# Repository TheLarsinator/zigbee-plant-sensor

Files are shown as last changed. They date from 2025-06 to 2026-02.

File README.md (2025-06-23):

# Zigbee Plant Sensor

This repository contains a project for creating a Zigbee Plant Sensor end device. The end goal is to create an energy efficient, battery powered solution for monitoring house plants. The device should be battery powered, and ideally last 2 months on a 1200 mAh battery.

When installed and powered, the device will report:

- Soil Moisture
- Illuminance
- Ambient Temperature
- Ambient Humidity
- Remaining Battery

The project is tested and developed for integrating with Zigbee2MQTT and Home Assistant.

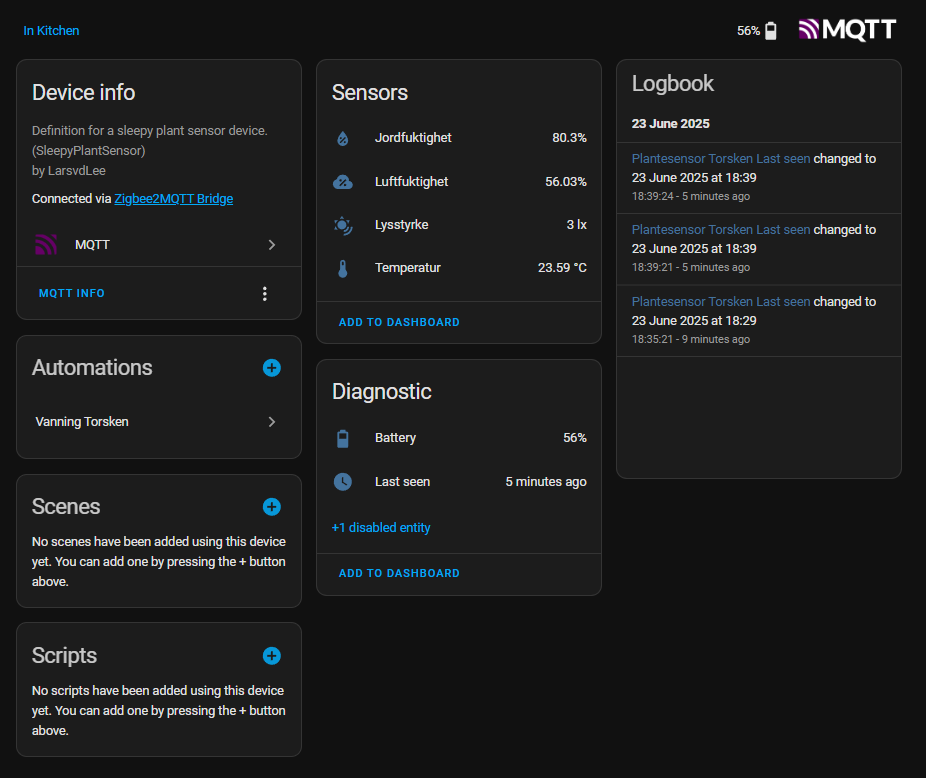
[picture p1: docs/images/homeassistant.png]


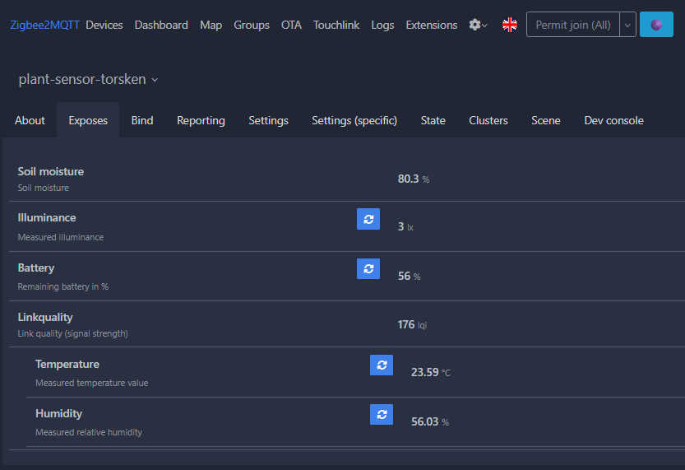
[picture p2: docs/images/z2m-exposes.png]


## Electrical Hardware
The current version of the device uses the following components:

- Custom PCB (Part of this repository)
- XIAO ESP32-C6
- AHT30 breakout module
    - Can be subsituted for a BME280 if a barometer is desired
- BH1750 breakout module
- HW390 capacitive moisture sensor
- 2x 200k Ohm resistors
- 2x 4 pin female header
- 2x 7 pin female header
- 2 pin screw terminal
- JST-PH female SMD connector
- LiPo battery with JST-PH connector (I use [this](https://www.kjell.com/no/produkter/elektro-og-verktoy/elektronikk/utviklerkit/arduino/arduino-tilbehor/luxorparts-li-po-batteri-37-v-med-kontakt-1200-mah-p87924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))

## Software
The current version of the software is developed using the Arduino platform, and is delivered in the form of a single sketch. Required libraries are:

- Zigbee from [Espressif's ESP32 Arduino Board](https://github.com/espressif/arduino-esp32)
- AHT20 from [AHT20](https://github.com/dvarrel/AHT20)
- BH1750 fom [BH1750](https://github.com/claws/BH1750)

## Mechanical Hardware
The current casing can be 3D printed using the STLs in the 3d-prints folder. I have succesfully printed these in PETG, however the casing is hard to assemble without breaking. The design has to be improved. Known issues:

- Lid is hard to attach as the lips on the casing are fragile
- The PCB cannot be angled enough with the PCB through the slit to slide onto the sticks

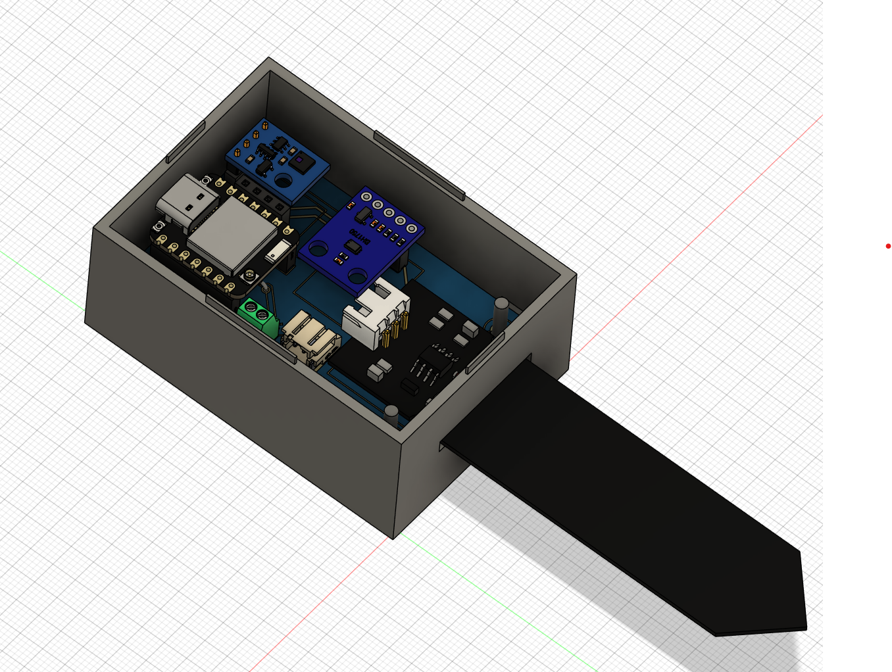
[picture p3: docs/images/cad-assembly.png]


## Assembly Instructions

1. Solder the following components onto the PCB:
    - 7-pin headers
    - 4-pin headers
        - Use the horizontal 4-pin header marked temperature if the AHT30 is to be used.
        - Use the vertical 4-pin header marked barometer if the BME280 is to be used.
    - 2-pin screw terminal
    - JST-PH female SMD connector
    - HW390 moisture sensor

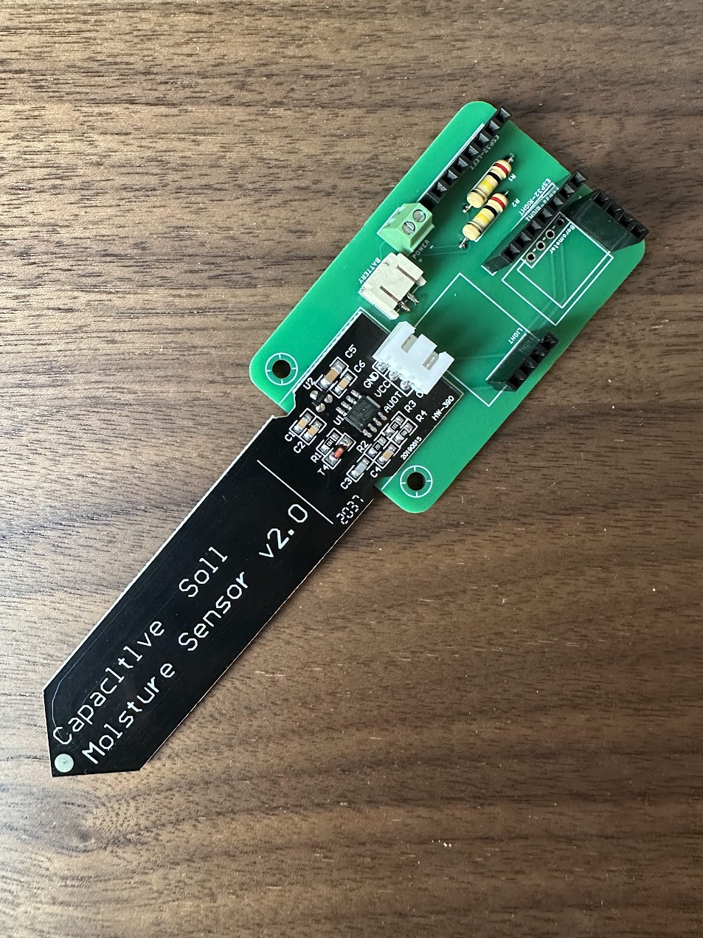
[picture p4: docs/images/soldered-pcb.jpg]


2. Solder a positive and negative wire to the battery pins of the XIAO ESP32-C6

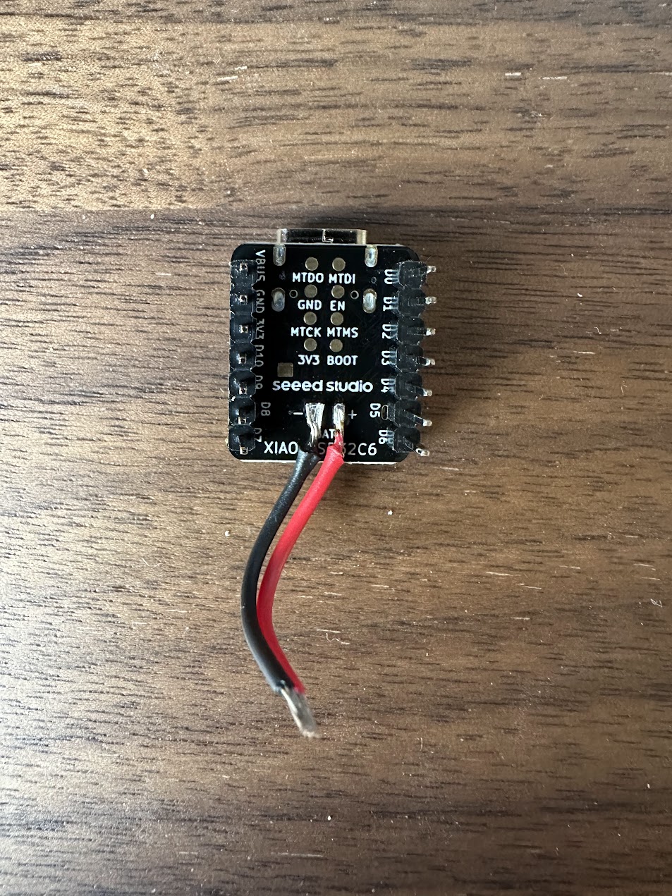
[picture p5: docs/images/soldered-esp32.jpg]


3. Connect the wires of the XIAO ESP32-C6 to the screw terminal. Note the polarity!

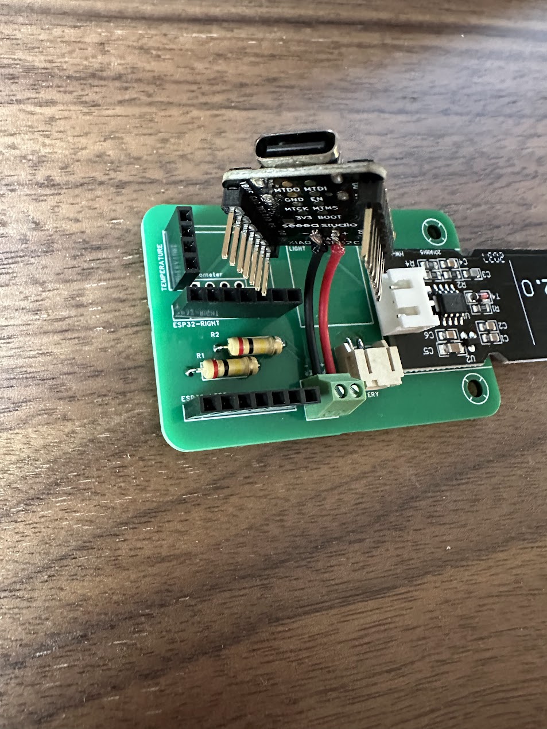
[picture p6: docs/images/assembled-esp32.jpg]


4. Mount the AHT30/BME280 and the BH1750 to the 4-pin headers. The PCB is now ready.

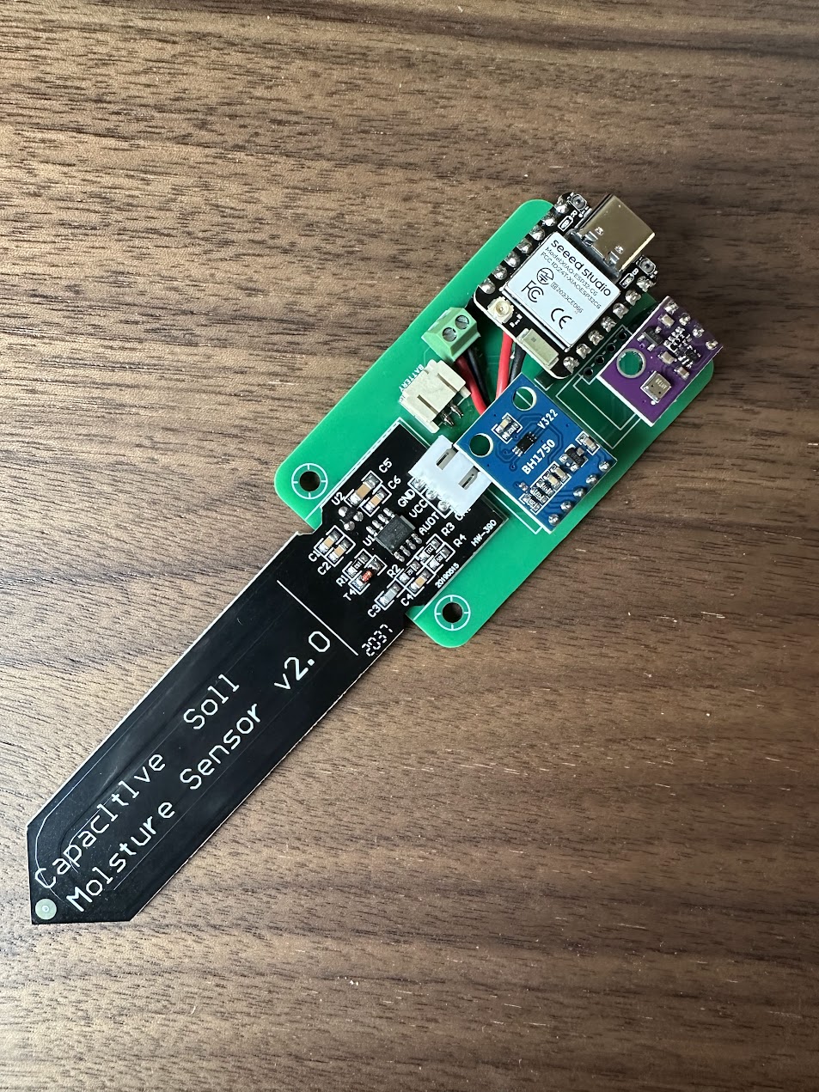
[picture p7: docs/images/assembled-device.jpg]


5. The battery goes into the bottom of the case. Connect it to the PCB and slide the PCB in. Finally close the lid and install the device in a plant pot.

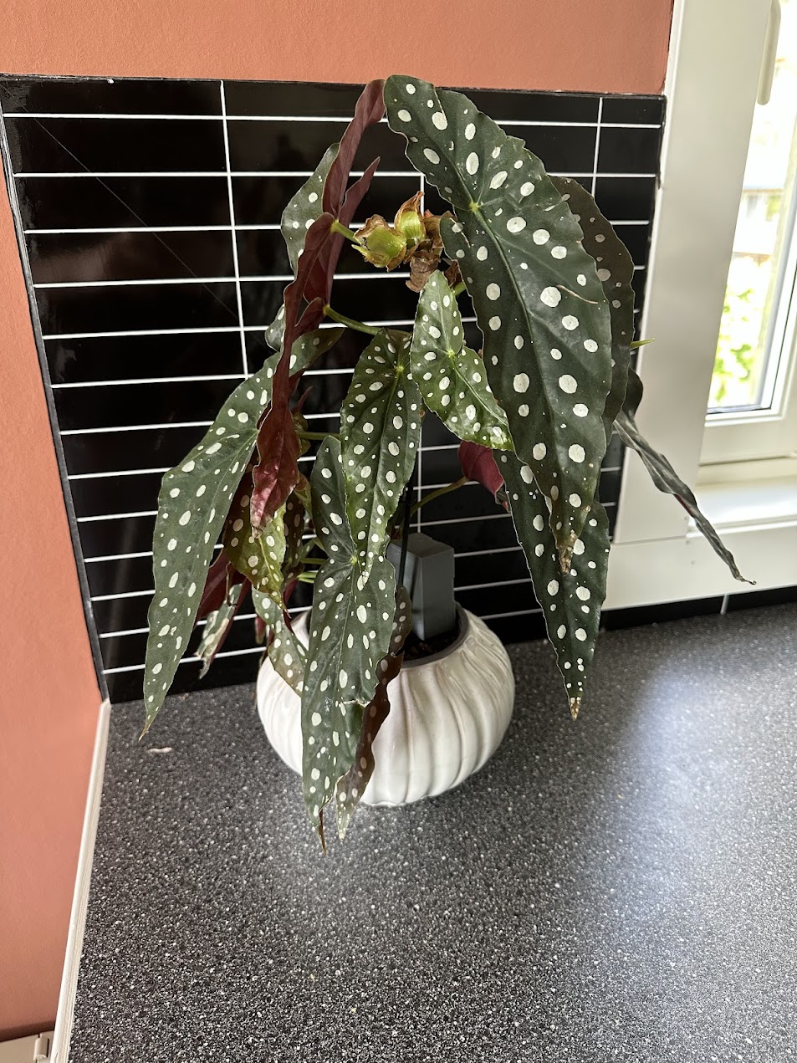
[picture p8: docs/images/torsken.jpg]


## Understanding the blinking
The onboard LED on the XIAO ESP32-C6 will blink with the following patterns:

- Slow blinking for 3 seconds
    - Occurs when the device is connecting to the Zigbee Network
- Slow blinking for 10 seconds
    - Occurs when the boot button was pressed and is kept pressed after the Zigbee Connect. This will result in a Zigbee Factory Reset.
- Fast blinking for 45 seconds
    - Occurs the first 2 boots, to give the devices time to complete the interview procedure

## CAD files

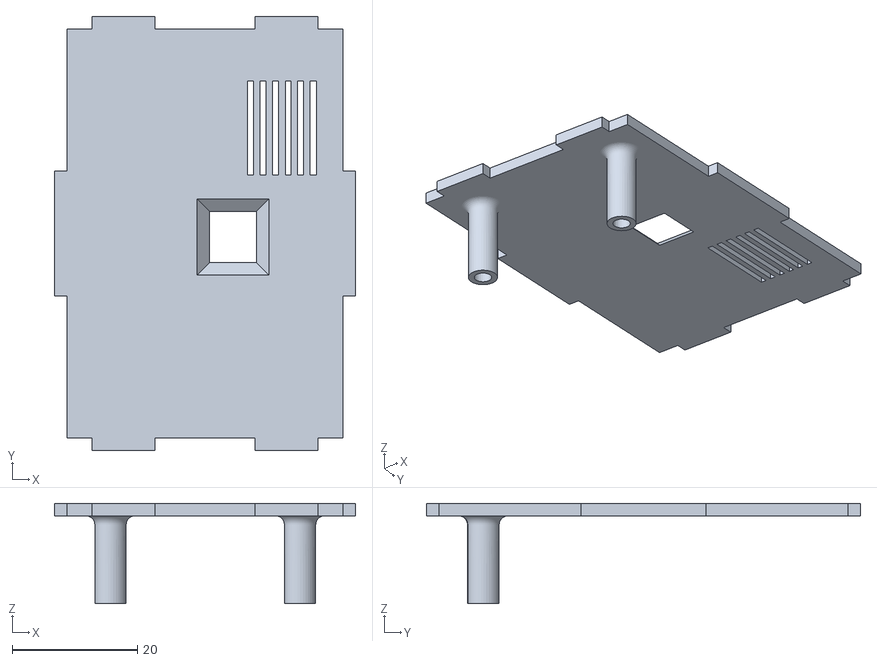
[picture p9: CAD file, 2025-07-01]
3d-prints/battery/lid.stl
48.0 x 69.2 x 16.0

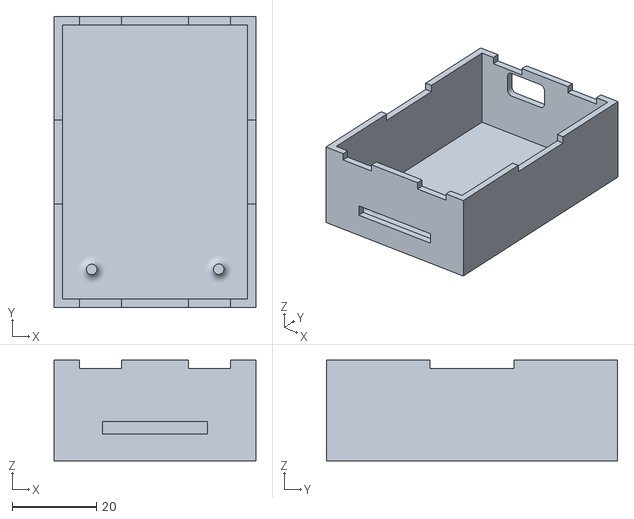
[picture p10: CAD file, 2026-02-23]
3d-prints/no-battery/plant-sensor-casing-no-battery.stl
48.0 x 69.2 x 24.0

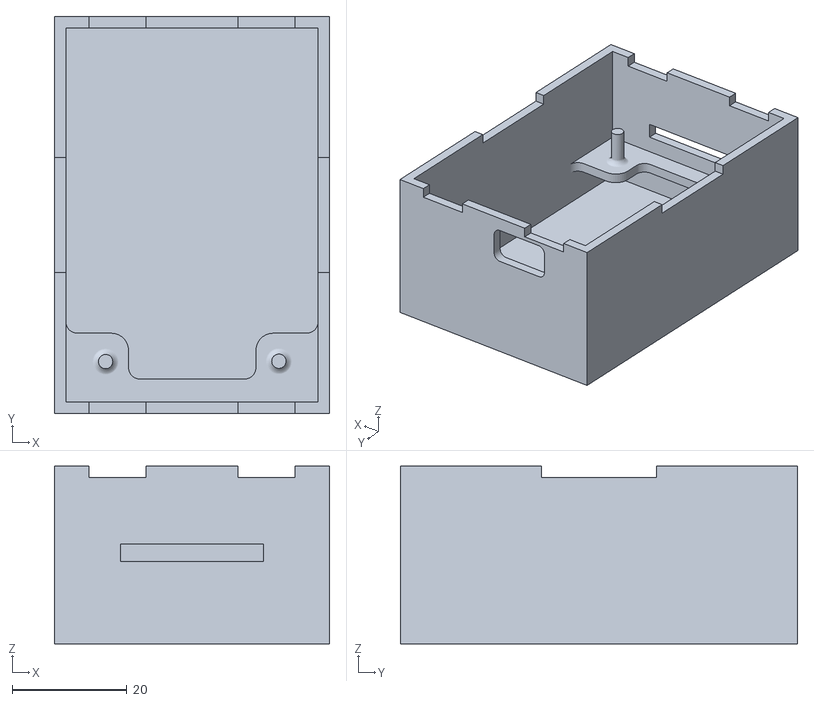
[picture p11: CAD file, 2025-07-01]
3d-prints/battery/plant-sensor-casing-usb-port.stl
48.0 x 69.2 x 31.0

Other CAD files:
3d-prints/no-battery/lid-no-battery.stl
3d-prints/battery/plant-sensor-casing.stl

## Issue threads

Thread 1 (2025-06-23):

Improve battery percentage calculation

TheLarsinator, 2025-06-23:
Perform a battery test, and create a decent discharge curve over time. Use this to create a more accurate approach for determining the battery percentage remaining.

TheLarsinator, 2025-06-23:
Input from Discord chat: https://github.com/def1149/ESP32_Stuff/blob/main/Lipo_Battery_Pct_Capacity

Closed 2025-06-24.

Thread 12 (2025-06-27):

Redesign PCB to allow turning the soil moisture sensor on/off

TheLarsinator, 2025-06-27:
Measurements using an INA219 showed that the moisture sensor was drawing 5.5 mA continously when powered directly from the 3V3 pin of the ESP32. That alone will empty the battery in about 10 days, meaning any other attempts to decrease power usage are futile achieving the goal of 2 months of operation.

As the current draw is less than 40 mA we can power the sensor directly from a GPIO pin. The PCB should be redesigned to allow for this.

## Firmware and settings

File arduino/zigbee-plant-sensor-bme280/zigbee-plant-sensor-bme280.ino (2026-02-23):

#ifndef ZIGBEE_MODE_ED
#error "Zigbee end device mode is not selected in Tools->Zigbee mode"
#endif

#include "Zigbee.h"
#include <Adafruit_Sensor.h>
#include <Adafruit_BME280.h>
#include <BH1750.h>
#include <math.h>

#define ZIGBEE_ILLUMINANCE_SENSOR_ENDPOINT 9
#define TEMP_SENSOR_ENDPOINT_NUMBER 10
#define MOISTURE_SENSOR_ENDPOINT_NUMBER 11
#define BATTERY_VOLTAGE_ENDPOINT_NUMBER 12
#define PRESSURE_ENDPOINT_NUMBER 13

#define uS_TO_S_FACTOR 1000000ULL /* Conversion factor for micro seconds to seconds */
#define TIME_TO_SLEEP  60

#define BATTERY_PIN A0
#define SOIL_PIN A1
#define SOIL_POWER_PIN 19

#define SLOW_BLINK_SPEED 500
#define FAST_BLINK_SPEED 250

#define BOOT_DELAY 2500
#define PAIRING_DELAY 30000
#define TRANSMISSION_DELAY 100
#define SOIL_MOISTURE_POWER_DELAY 500
#define LIGHT_MEASUREMENT_TIMEOUT 500
#define LIGHT_MEASUREMENT_POLL_DELAY 10

#define SLOW_BOOTS 2

float soil_moisture_lower_limit = 1000;
float soil_moisture_upper_limit = 2600;

ZigbeeIlluminanceSensor zbIlluminanceSensor = ZigbeeIlluminanceSensor(ZIGBEE_ILLUMINANCE_SENSOR_ENDPOINT);
BH1750 light_sensor;
bool lightSensorDetected = false;

ZigbeeTempSensor zbTempSensor = ZigbeeTempSensor(TEMP_SENSOR_ENDPOINT_NUMBER);
ZigbeePressureSensor zbPressureSensor = ZigbeePressureSensor(PRESSURE_ENDPOINT_NUMBER);
Adafruit_BME280 bme;
bool bmeDetected = false;

ZigbeeAnalog zbSoilMoistureSensor = ZigbeeAnalog(MOISTURE_SENSOR_ENDPOINT_NUMBER);
ZigbeeAnalog zbBatteryVoltage = ZigbeeAnalog(BATTERY_VOLTAGE_ENDPOINT_NUMBER);

RTC_DATA_ATTR int bootCount = 0;
RTC_DATA_ATTR int lastBatteryPercentage = -10;
RTC_DATA_ATTR int lastSoilMoisturePercentage = -10;

void enableExternalAntenna()
{
  pinMode(WIFI_ENABLE, OUTPUT); // pinMode(3, OUTPUT);
  digitalWrite(WIFI_ENABLE, LOW); // digitalWrite(3, LOW); // Activate RF switch control

  delay(100);

  pinMode(WIFI_ANT_CONFIG, OUTPUT); // pinMode(14, OUTPUT);
  digitalWrite(WIFI_ANT_CONFIG, HIGH); // digitalWrite(14, HIGH); // Use external antenna
}

void blinkAndWait(int delayMillis, long speed)
{
  int startTime = millis();
  while ((millis() - startTime) < delayMillis)
  {
    digitalWrite(LED_BUILTIN, LOW);
    delay(speed);
    digitalWrite(LED_BUILTIN, HIGH);
    delay(speed);
  }
}

void setBmeSleepMode()
{
  if (bmeDetected)
  {
    bme.setSampling(Adafruit_BME280::MODE_SLEEP);
  }
}

void goToSleep()
{
  setBmeSleepMode();

  // Configure the wake up source and go to sleep.
  esp_sleep_enable_timer_wakeup(TIME_TO_SLEEP * uS_TO_S_FACTOR);
  esp_deep_sleep_start();
}

int measureBatteryPercentage()
{
  // Measure 16 times and take the average.
  uint32_t batteryVoltages = 0;
  for(int i = 0; i < 16; i++) {
    batteryVoltages += analogReadMilliVolts(BATTERY_PIN);
  }
  float batteryVoltage = 2 * batteryVoltages / 16;
  float batteryPercentage = getBatteryPercentage(batteryVoltage);
  return roundPercentageDown(batteryPercentage, 10);
}

void reportBatteryPercentage(float batteryPercentage)
{
  // Update.
  zbTempSensor.setBatteryPercentage(batteryPercentage);

  // Report.
  zbTempSensor.reportBatteryPercentage();
}

float measureSoilMoisture()
{
    // Power the soil moisture sensor.
    digitalWrite(SOIL_POWER_PIN, HIGH);
    delay(SOIL_MOISTURE_POWER_DELAY); // Allow the sensor to stabilize.

    // Measure 16 times and take the average.
    uint32_t moistureReadings = 0;
    for(int i = 0; i < 16; i++) {
      moistureReadings += analogRead(SOIL_PIN); // Read and accumulate ADC voltage
    }

    // Power off the soil moisture sensor.
    digitalWrite(SOIL_POWER_PIN, LOW);

    float moistureReading = moistureReadings / 16;
    // We assume the HW390 behaves linearly between the lower and upper limit.
    float moisturePercentage = (1 -((moistureReading - soil_moisture_lower_limit) / (soil_moisture_upper_limit - soil_moisture_lower_limit))) * 100;
    Serial.println(moisturePercentage);
    return roundPercentageDown(moisturePercentage, 5);
}

void reportSoilMoisture(float soilMoisturePercentage)
{
  // Update.
  int soilMoisturePercentageScaled = soilMoisturePercentage * 10;
  zbSoilMoistureSensor.setAnalogInput(soilMoisturePercentageScaled);

  // Report.
  zbSoilMoistureSensor.reportAnalogInput();
}

int measureIlluminance()
{
  if (!lightSensorDetected)
  {
    return -1;
  }

  int waitTime = 0;
  while (!light_sensor.measurementReady() && waitTime < LIGHT_MEASUREMENT_TIMEOUT)
  {
    delay(LIGHT_MEASUREMENT_POLL_DELAY);
    waitTime += LIGHT_MEASUREMENT_POLL_DELAY;
  }

  if (!light_sensor.measurementReady())
  {
    Serial.println("BH1750 measurement timeout.");
    return -1;
  }

  return round(light_sensor.readLightLevel());
}

void reportIlluminance(int illuminance)
{
  if (illuminance < 0)
  {
    return;
  }
  // Update.
  int zigbee_illuminance = 10000 * log10(illuminance);
  zbIlluminanceSensor.setIlluminance(zigbee_illuminance);

  // Report.
  zbIlluminanceSensor.report();
}

void measureTemperatureAndHumidity(float* temperature, float* humidity)
{
  // Measure.
  *temperature =  bme.readTemperature();
  *humidity = bme.readHumidity();

  Serial.println(*temperature);
  Serial.println(*humidity);
}

void reportTemperatureAndHumidity(float temperature, float humidity)
{
  // Update.
  zbTempSensor.setTemperature(temperature);
  zbTempSensor.setHumidity(humidity);

  // Report.
  zbTempSensor.report();
}

void measurePressure(float* pressure)
{
  // Measure.
  *pressure =  bme.readPressure() / 100.0F;
  Serial.println(*pressure);
}

void reportPressure(float pressure)
{
  // Update.
  zbPressureSensor.setPressure((int)pressure);

  // Report.
  zbPressureSensor.report();
}

float getBatteryPercentage(int milliVolts) {
  // Model taken from: https://github.com/def1149/ESP32_Stuff/blob/main/Lipo_Battery_Pct_Capacity
  #define FULL 4200   // >= FULL 100%
  #define EMPTY 3499  // < EMPTY 0%
  float percentage;

  if (milliVolts >= FULL) {
    percentage = 100.0;
  } 
  else if (milliVolts >= 3880) {
    percentage = map(milliVolts,3880,FULL-1,600,999)/10.0;
  } 
  else if (milliVolts >= 3750) {
    percentage = map(milliVolts,3750,3879,202,599)/10.0;
  }
  else if (milliVolts >= 3700 ) {
    percentage = map(milliVolts,3700,3749,79,201)/10.0;
  }
  else if (milliVolts >= 3610 ) {
    percentage = map(milliVolts,3610,3699,20,78)/10.0;
  }
  else if (milliVolts >= EMPTY) {
    percentage = map(milliVolts,EMPTY,3609,1,19)/10.0;
  }
  else {
    percentage = 0.0;
  }

  return percentage;
}

int roundPercentageDown(int percentage, int remainder)
{
  return percentage - (percentage % remainder);
}

void configureZigbeeStack()
{
  // Set Zigbee device name and model
  zbTempSensor.setManufacturerAndModel("LarsvdLee", "SleepyPlantSensorWithPressure");

  // Set minimum and maximum temperature measurement value.
  zbTempSensor.setMinMaxValue(10, 50);

  // Set tolerance for temperature measurement in °C (lowest possible value is 0.01°C)
  zbTempSensor.setTolerance(1);

  // Set power source to battery and set battery percentage to the last measured value.
  zbTempSensor.setPowerSource(ZB_POWER_SOURCE_BATTERY, lastBatteryPercentage);

  // Add humidity cluster to the temperature sensor device with min, max and tolerance values
  zbTempSensor.addHumiditySensor(0, 100, 1);

  // Set minimum and maximum for raw illuminance value (0 min and 50000 max equals to 0 lux - 100,000 lux)
  zbIlluminanceSensor.setMinMaxValue(0, 50000);

  // Set tolerance for raw illuminance value
  zbIlluminanceSensor.setTolerance(1);

  // Setup the analog device.
  // zbSoilMoistureSensor.addAnalogInput();
  analogReadResolution(12);

  // Setup the pressure endpoint.
  // Set minimum and maximum pressure measurement value in hPa
  zbPressureSensor.setMinMaxValue(0, 10000);

  // Optional: Set tolerance for pressure measurement in hPa
  zbPressureSensor.setTolerance(1);

  // Add endpoints to Zigbee Core
  Zigbee.addEndpoint(&zbIlluminanceSensor);
  Zigbee.addEndpoint(&zbTempSensor);
  // Zigbee.addEndpoint(&zbSoilMoistureSensor);
  Zigbee.addEndpoint(&zbPressureSensor);

  // For battery powered devices, it can be better to set timeout for Zigbee Begin to lower value to save battery
  // If the timeout has been reached, the network channel mask will be reset and the device will try to connect again after reset (scanning all channels)
  Zigbee.setTimeout(10000);  // Set timeout for Zigbee Begin to 10s (default is 30s)
}

void startZigbee()
{
  // Create a custom Zigbee configuration for End Device with keep alive 10s to avoid interference with reporting data
  esp_zb_cfg_t zigbeeConfig = ZIGBEE_DEFAULT_ED_CONFIG();
  zigbeeConfig.nwk_cfg.zed_cfg.keep_alive = 20000;

  // When all EPs are registered, start Zigbee in End Device mode
  if (!Zigbee.begin(&zigbeeConfig, false)) {
    Serial.println("Zigbee failed to start!");
    Serial.println("Rebooting...");
    ESP.restart();  // If Zigbee failed to start, reboot the device and try again
  }
  Serial.println("Connecting to network");
  while (!Zigbee.connected()) {
    Serial.print(".");
    delay(100);
  }
  Serial.println();
  Serial.println("Successfully connected to Zigbee network");

  zbTempSensor.setReporting(120, 120, 10);
  zbTempSensor.setHumidityReporting(120,120,10);
  zbIlluminanceSensor.setReporting(120, 120, 10);
  // zbSoilMoistureSensor.setAnalogInputReporting(120, 120, 10);
  zbPressureSensor.setReporting(0, 60, 0.1);
}

/********************* Arduino functions **************************/
void setup() {
  Serial.begin(115200);
  Serial.print("Booting for the ");
  Serial.print(++bootCount);
  Serial.println("th time.");

  // Init BOOT_PIN switch
  pinMode(BOOT_PIN, INPUT_PULLUP);
  pinMode(LED_BUILTIN, OUTPUT);
  pinMode(SOIL_PIN, INPUT);
  pinMode(BATTERY_PIN, INPUT);
  pinMode(SOIL_POWER_PIN, OUTPUT);

  // enableExternalAntenna();

  // Connect to AHT30 sensor.
  Wire.begin();
  lightSensorDetected = light_sensor.begin();
  if (!lightSensorDetected) {
    Serial.println("BH1750 not detected. Please check wiring.");
  }
  light_sensor.configure(BH1750::ONE_TIME_HIGH_RES_MODE_2);

  bmeDetected = bme.begin(0x76);
  if (bmeDetected == false)
  {
    Serial.println("BME280 not detected. Please check wiring.");
  }

  configureZigbeeStack();
  startZigbee();
}

void loop() {
  // Smal delay to allow establishing a proper connection with the coordinator. Done before the loop to allow for pressing the boot button after starting.
  blinkAndWait(BOOT_DELAY, SLOW_BLINK_SPEED);

  // Checking BOOT_PIN for factory reset
  if (digitalRead(BOOT_PIN) == LOW) {  // Push BOOT_PIN pressed
    // Key debounce handling
    delay(100);
    int startTime = millis();
    while (digitalRead(BOOT_PIN) == LOW) {
      delay(SLOW_BLINK_SPEED);
      if ((millis() - startTime) > 10000) {
        // If key pressed for more than 10secs, factory reset Zigbee and reboot
        Serial.println("Resetting Zigbee to factory and rebooting in 1s.");
        delay(1000);
        // Optional set reset in factoryReset to false, to not restart device after erasing nvram, but set it to endless sleep manually instead
        Zigbee.factoryReset(false);
        Serial.println("Going to endless sleep, press RESET BOOT_PIN or power off/on the device to wake up");

        esp_sleep_disable_wakeup_source(ESP_SLEEP_WAKEUP_TIMER);
        esp_deep_sleep_start();
      }
      digitalWrite(LED_BUILTIN, LOW);
      delay(SLOW_BLINK_SPEED);
      digitalWrite(LED_BUILTIN, HIGH);
    }
  }

  // The initial pairing is slower, so we wait longer the first 2 times we boot before sending data.
  if (bootCount < SLOW_BOOTS)
  {
    blinkAndWait(PAIRING_DELAY, FAST_BLINK_SPEED);
  }

  int batteryPercentage = measureBatteryPercentage();

  if (batteryPercentage != lastBatteryPercentage)
  {
    lastBatteryPercentage = batteryPercentage;
    reportBatteryPercentage(batteryPercentage);
  }

  int illuminance = measureIlluminance();
  if (illuminance >= 0)
  {
    reportIlluminance(illuminance);
  }

  float soilMoisture = measureSoilMoisture();
  if (soilMoisture != lastSoilMoisturePercentage)
  {
    lastSoilMoisturePercentage = soilMoisture;
    reportSoilMoisture(soilMoisture);
  }

  float temperature, humidity;
  measureTemperatureAndHumidity(&temperature, &humidity);
  reportTemperatureAndHumidity(temperature, humidity);
  
  float pressure;
  measurePressure(&pressure);
  reportPressure(pressure);
  Serial.println("DONE");
  // Small delay to allow all reporting to finish.
  delay(TRANSMISSION_DELAY);

  goToSleep();
}

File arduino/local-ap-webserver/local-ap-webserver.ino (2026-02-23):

#include <WiFi.h>
#include <WebServer.h>
#include <ArduinoJson.h>
#include <Wire.h>
#include <AHT20.h>
#include <BH1750.h>
#include <Preferences.h>

// AP credentials
const char* ssid = "PlantSensor_ZPS00X";
const char* password = "ZPS00X-P";

WebServer server(80);

#define MAX_MEASUREMENTS 288
#define SOIL_MOISTURE_PIN A1

AHT20 aht;  // AHT30 sensor
BH1750 lightMeter;

Preferences preferences;
float temperatureOffset = 0.0;
int soilMoistureMin = 0.0;
int soilMoistureMax = 0.0;

struct Measurement {
  float temp;
  float hum;
  float illum;
  float soil;
};

Measurement measurements[MAX_MEASUREMENTS];
int writeIndex = 0;
int storedCount = 0;

unsigned long lastMeasurementMillis = 0;
const unsigned long measurementInterval = 900000; // 1 hour = 3600000 ms

void setup() {
  Serial.begin(115200);
  delay(1000);
  Wire.begin();
  aht.begin();
  lightMeter.begin(BH1750::CONTINUOUS_HIGH_RES_MODE);

  // Start WiFi AP
  WiFi.softAP(ssid);
  IPAddress IP = WiFi.softAPIP();
  Serial.print("AP IP address: ");
  Serial.println(IP);

  // Initialize measurements with zeros
  for (int i = 0; i < MAX_MEASUREMENTS; i++) {
    measurements[i] = {0,0,0,0};
  }

  preferences.begin("calibration", false);
  temperatureOffset = preferences.getFloat("tempOffset", 0.0);
  soilMoistureMin = preferences.getInt("soilMoistureMin", 0.0);
  soilMoistureMax = preferences.getInt("soilMoistureMax", 0.0);

  // Setup web server routes
  server.on("/", handleRoot);
  server.on("/data", handleData);
  server.on("/set_offset", HTTP_POST, handleSetOffset);
  server.on("/config", handleConfig);

  server.begin();
  Serial.println("HTTP server started");
}

void loop() {
  server.handleClient();

  unsigned long now = millis();
  if (now - lastMeasurementMillis >= measurementInterval || lastMeasurementMillis == 0) {
    lastMeasurementMillis = now;
    takeMeasurement();
  }
}

// Simulated sensor reading function — replace with real sensors
void takeMeasurement() {
  float t = aht.getTemperature();
  float h = aht.getHumidity();
  float i = lightMeter.readLightLevel();
  float s = (1 - ((analogRead(SOIL_MOISTURE_PIN) - soilMoistureMin) / (soilMoistureMax + 1.0F - soilMoistureMin))) * 100;

  addMeasurement(t,h,i,s);

  Serial.printf("Measured: T=%.2f, H=%.2f, Illum=%.1f, Soil=%.3f\n", t, h, i, s);
}

void addMeasurement(float t, float h, float i, float s) {
  measurements[writeIndex] = {t,h,i,s};
  writeIndex = (writeIndex + 1) % MAX_MEASUREMENTS;
  if (storedCount < MAX_MEASUREMENTS) storedCount++;
}

void handleData() {
  DynamicJsonDocument doc(4096);
  JsonArray arr = doc.to<JsonArray>();

  int oldestIndex = (writeIndex + MAX_MEASUREMENTS - storedCount) % MAX_MEASUREMENTS;
  
  for (int i = 0; i < storedCount; i++) {
    int idx = (oldestIndex + i) % MAX_MEASUREMENTS;
    JsonObject obj = arr.createNestedObject();
    obj["hoursAgo"] = storedCount - 1 - i;  // 0 newest, increasing backwards
    obj["temp"] = measurements[idx].temp + temperatureOffset;
    obj["hum"] = measurements[idx].hum;
    obj["illum"] = measurements[idx].illum;
    obj["soil"] = measurements[idx].soil;
  }

  String output;
  serializeJson(doc, output);
  server.send(200, "application/json", output);
}

void handleSetOffset() {
  if (server.hasArg("plain") == false) {
    server.send(400, "application/json", "{\"error\":\"Missing body\"}");
    return;
  }

  String body = server.arg("plain");
  StaticJsonDocument<200> doc;
  DeserializationError error = deserializeJson(doc, body);

  if (error) {
    server.send(400, "application/json", "{\"error\":\"Invalid JSON\"}");
    return;
  }

  float offsetNew = doc["offset"] | 0.0;
  int soilMinNew = doc["soilMin"] | 0.0;
  int soilMaxNew = doc["soilMax"] | 0.0;

  if (offsetNew != 0.0 && offsetNew != temperatureOffset) {
    preferences.putFloat("tempOffset", offsetNew);
    Serial.printf("New temperature offset: %.2f\n", offsetNew);
    temperatureOffset = offsetNew;
  }
  if (soilMinNew != 0.0 && soilMinNew != soilMoistureMin) {
    preferences.putInt("soilMoistureMin", soilMinNew);
    Serial.print("New soil moisture min: ");
    Serial.println(soilMinNew);
    soilMoistureMin = soilMinNew;
  }
  if (soilMaxNew != 0.0 && soilMaxNew != soilMoistureMax) {
    preferences.putInt("soilMoistureMax", soilMaxNew);
    Serial.print("New soil moisture max: ");
    Serial.println(soilMaxNew);
    soilMoistureMax = soilMaxNew;
  }

  server.send(200, "application/json", "{\"status\":\"ok\"}");
}

void handleConfig() {
  StaticJsonDocument<200> json;

  json["tempOffset"] = temperatureOffset; // existing
  json["soilMin"] = soilMoistureMin;  // new
  json["soilMax"] = soilMoistureMax;  // new

  String response;
  serializeJson(json, response);
  server.send(200, "application/json", response);
}
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

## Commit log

2025-06-19 Initial commit of arduino sketch and z2m converter
2025-06-19 Added PCB design project
2025-06-23 Add 3D print files and add more documentation
    [lid.stl, plant-sensor-casing.stl]
2025-06-24 Add a battery model instead of a linear mapping
2025-06-24 Redesign of casing (#9)
    [lid.stl, plant-sensor-casing.stl]
2025-06-24 Restructure the Arduino folder to allow opening the sketch in Arduino IDE
2025-06-25 Update lid to make it fit tighter (#11)
    [lid.stl]
2025-06-27 Updated the PCB to connect the power pin of the soil moisture sensor to the D8 pin on the XIAO ESP32-C6 (#13)
2025-07-01 WiFi sketch and casing (#14)
    * Add sketches for webservers over WiFi/Local AP
    Add casing with USB-C opening
    * Set timings to 1 hour
    * Updated the UI and extended to 72 hours of data
    * Added tighter tolerance lids and a casing without a battery slot
    * Rename lid files for clarity
    [lid-0-tolerance.stl, lid-0_05-tolerance.stl, lid-0_1-tolerance.stl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]
2026-02-23 Power improvements (#15)
    * Refactor battery and soil moisture measurement functions for reduced reporting by rounding down to round numbers and only reporting new values
    * Code changes for supporting rev 1.1 PCB, where soil moisture sensor is powered through GPIO 19
    * WIP on BME and Reporting rates
    * Always report
    * Set sensors to sleep mode to save power
    * Add MQTT app and more power optimization for the zigbee app.
2026-02-23 Add calibration to wifi sketches (#16)
    * Added calibration to the wifi sketches
    * Remove local AP password and take measurement on first boot
2026-02-23 Improve no-battery casing and delete all loose lids (#17)
    [lid-0_05-tolerance.stl, lid-0_1-tolerance.stl, lid-no-battery.stl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]
2026-11-12 Report genAnalogInput metadata so Zigbee2MQTT can skip startup reads
    Zigbee2MQTT 2.14 reads description, applicationType, engineeringUnits,
    min/maxPresentValue and resolution from genAnalogInput on endpoint 11 at
    startup. The plant sensor sleeps, so each read times out after 10 s and
    Z2M startup takes ~15 minutes (Koenkk/zigbee2mqtt#33470). Z2M skips a
    read when it has a cached value, and it caches values from reports.
    - Set description "Soil moisture", application type 4 (percentage, so Z2M
    derives "%" and skips the engineeringUnits read), min/max 0..1000
    (percent x 10) and resolution 1 on the soil moisture analog input.
    - Report those five attributes on the first boot after power-up a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
2026-11-12 Stop reporting the analog input description attribute
    Forcing the REPORTING flag on description (0x001C, a character string)
    makes esp_zb_zcl_report_attr_cmd_req() hit a Zigbee stack assertion
    (esp_zigbee_zcl_command.c:263) right after joining, which aborts and
    reboots the sensor. Report only the numeric metadata attributes.
2026-11-12 Power/reduce awake time (#18)
    * Shorten awake time and sleep when the Zigbee network is unreachable
    - Power the soil moisture sensor first and read the AHT20 and BH1750
    while it stabilizes, all before the radio starts. The AHT20's ~80 ms
    measurement no longer runs with the radio on, and the soil sensor's
    500 ms warm-up is no longer pure idle time.
    - If Zigbee.begin() fails or joining takes longer than 10 s (30 s on the
    first boots, for pairing), deep sleep until the next wake-up instead
    of rebooting immediately or waiting forever with the radio on.
    * Measure the battery at rest, before the soil sensor and radio
    Under radio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
